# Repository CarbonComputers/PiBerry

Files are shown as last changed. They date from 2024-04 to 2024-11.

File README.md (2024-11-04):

# PiBerry v7.0-7.5 comes with built-in battery power, charging, and keyboard circuit
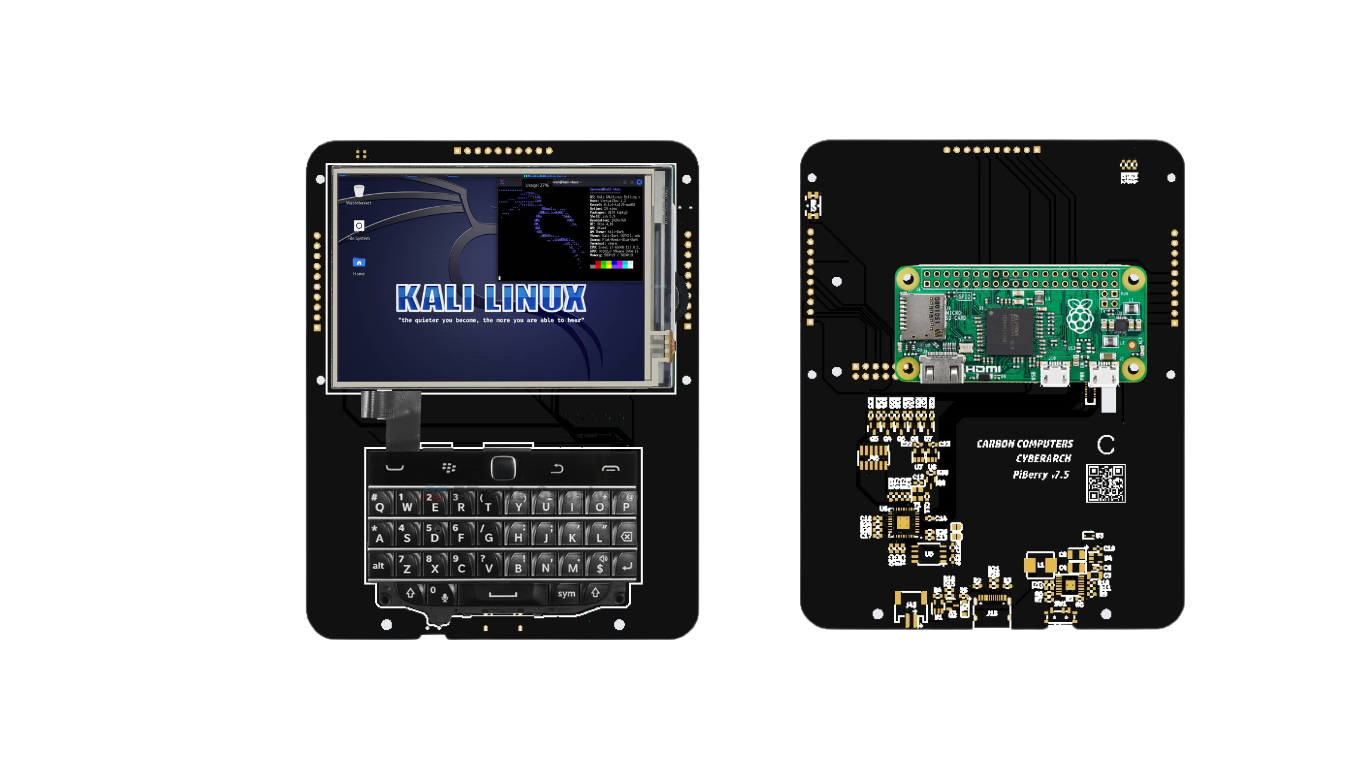
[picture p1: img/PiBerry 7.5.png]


# PiBerry v1.5-v1.8 for a plug & play build
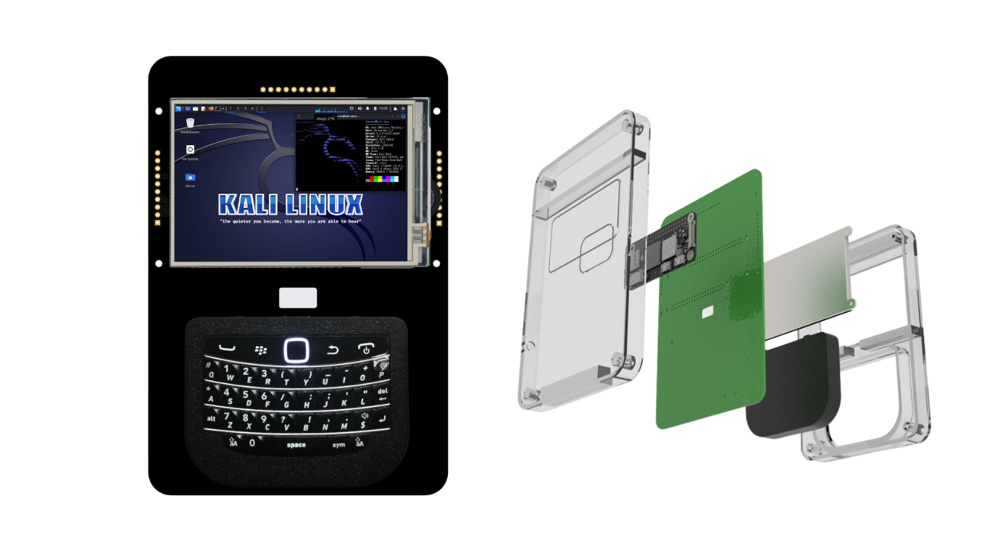
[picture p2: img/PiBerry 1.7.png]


### [Buy Ours Here](https://carboncomputers.us)

## Getting Started
Check the build-guide PDF for the lastest update on build and setup

1. Use the [Raspberry Pi Imager tool](https://www.raspberrypi.com/software/) to flash an SD card with the latest image
    - Choose the ***Raspberry Pi OS Lite (32-bit) image*** for best speed
    - Click the gear icon to also setup WiFi and SSH or you may use a display and keyboard

2. SSH into the pi and update the kernel and reboot
- If the Pi imager was used, then you have the latest kernel, and may then only use apt-get update, skip reboot, and continue onto part 3
```

sudo apt-get update && sudo apt-get install raspberrypi-kernel
```
```
sudo shutdown -r now
```

3. Run the setup script
```
curl -s https://raw.githubusercontent.com/carboncomputers/piberry/main/pi/setup.sh | bash
```

## Details
- In ```/boot/cmdline.txt```, edit ```fbcon=font:VGA8x8``` to change the font/size if you wish. See [fbcon](https://www.kernel.org/doc/Documentation/fb/fbcon.txt) for more details
- Long holding the "End Call" key (~3 seconds) will trigger KEY_POWER and safely shutdown the pi
- Holding the "End Call" button during power up will put the keyboard into bootloader mode; it will now appear as a USB storage device and you can drag'n'drop the new firmware (\*.uf2) into the drive and it will reboot with the new firmware

------------------------------------------------------------------------------------------------------------

# Giving Credit Where Credit is Due

# Beepy - THE ORIGINAL DEVELOPMENT BOARD - THANK YOU FOR MAKING IT OPEN SOURCE



### [Buy It Here - LIMITED STOCK](https://forms.gle/Q3NCLSjDZwcURxrs8)

Learn more at <a href="https://beepy.sqfmi.com/" target="_blank" rel="noopener noreferrer">https://beepy.sqfmi.com/</a>

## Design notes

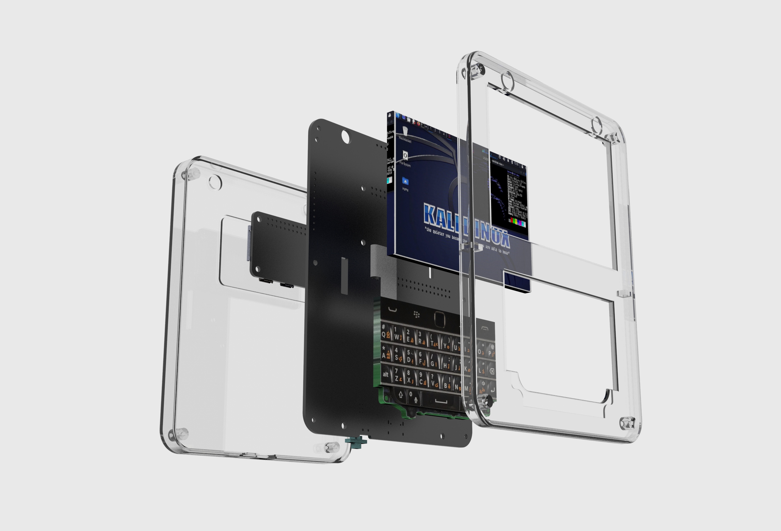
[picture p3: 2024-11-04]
img/v8.0_slim.jpg

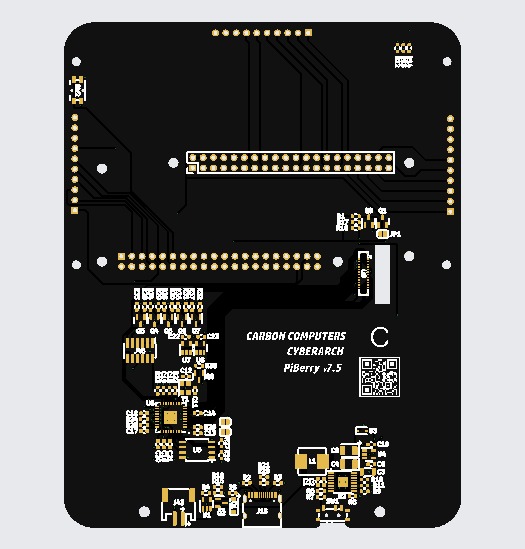
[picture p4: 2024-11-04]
img/PiBerry 7.5 back.jpeg

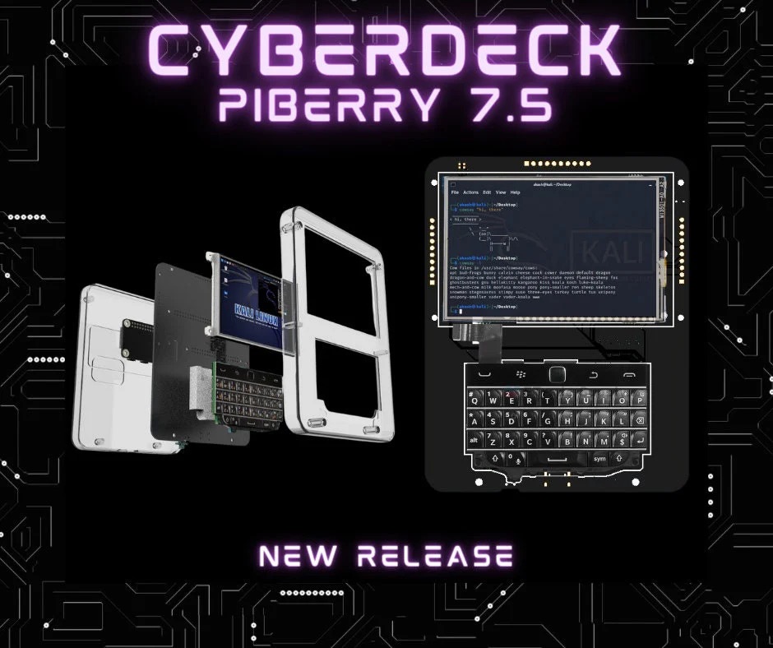
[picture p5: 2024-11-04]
img/7.5.jpeg

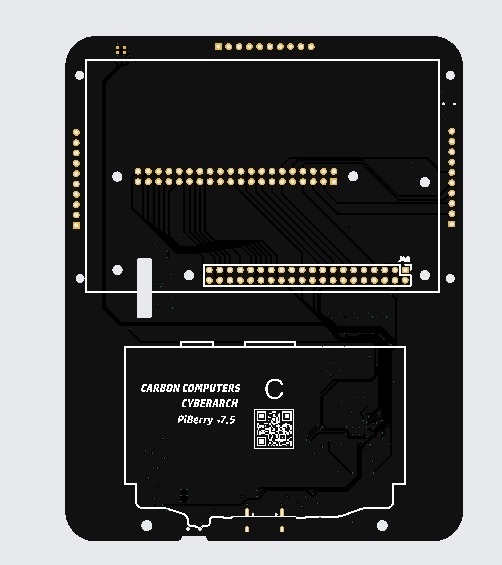
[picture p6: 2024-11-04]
img/PiBerry 7.5.jpeg

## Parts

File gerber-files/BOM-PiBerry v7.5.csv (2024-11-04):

Comment | Designator | Footprint | LCSC
BSS138 | Q3,Q4,Q5,Q6,Q7,Q8 | SOT-23 | C112239
D_Schottky_Small | D3 | D_SOD-323 | C114023
USB_C_Receptacle_USB2.0 | J15 | USB_C_Receptacle_HRO_TYPE-C-31-M-12 | C165948
ME6212C18M5G | U7 | SOT-23-5 | C236669
BBQ20KBD | U9 | BM20B(0.8)-40DS-0.4V | C424543
ME6212C28M5G | U8 | SOT-23-5 | C427596
AP2112K-3.3 | U4 | SOT-23-5 | C51118
XYDBPCNANF-12MHZ | Y1 | Crystal_SMD_3225-4Pin_3.2x2.5mm | C709001
GD25Q16xS | U5 | SSOP-8_5.25x5.24mm_P1.27mm | C79074
RPi_GPIO | J48 | PinHeader_2x20_P2.54mm_Vertical
Notification LED | D2 | FM-B2020RGBA-HG
10K | R1 | R_0603_1608Metric
1K | R22 | R_0603_1608Metric
TPS61090 | U2 | HTSSOP-16-1EP_4.4x5mm_P0.65mm_EP3.4x5mm_Mask2.46x2.31mm_ThermalVias
Button | SW2 | Panasonic_EVQPUL_EVQPUC
10K | R31 | R_0603_1608Metric
1uF | C21 | C_0603_1608Metric
22uF | C3 | C_1206_3216Metric
0.1uF | C17 | C_0603_1608Metric
0.1uF | C22 | C_0603_1608Metric
2M | R6 | R_0603_1608Metric
6.8uH/4A | L1 | L_Bourns_SRP7028A_7.3x6.6mm
220K | R11 | R_0603_1608Metric
27R | R20 | R_0603_1608Metric
100nF | C2 | C_0603_1608Metric
10K | R36 | R_0603_1608Metric
0.1uF | C14 | C_0603_1608Metric
10K | R28 | R_0603_1608Metric
10uF | C10 | C_0603_1608Metric
360K | R7 | R_0603_1608Metric
10K | R30 | R_0603_1608Metric
RP2040 | U6 | QFN-56-1EP_7x7mm_P0.4mm_EP5.6x5.6mm
1K | R27 | R_0603_1608Metric
10uF | C1 | C_0603_1608Metric
10K | R32 | R_0603_1608Metric
100K | R5 | R_0603_1608Metric
0.1uF | C15 | C_0603_1608Metric
4.7K | R25 | R_0603_1608Metric
12pF | C12 | C_0603_1608Metric
220 | R12 | R_0603_1608Metric
10K | R4 | R_0603_1608Metric
TP4054 | U1 | SOT-23-5
330 | R18 | R_0603_1608Metric
0.1uF | C19 | C_0603_1608Metric
10K | R23 | R_0603_1608Metric
10K | R19 | R_0603_1608Metric
27R | R21 | R_0603_1608Metric
100uF | C5 | CP_EIA-3528-15_AVX-H
10uF | C9 | C_0603_1608Metric
10K | R33 | R_0603_1608Metric
10K | R29 | R_0603_1608Metric
Battery | J43 | JST_PH_S2B-PH-SM4-TB_1x02-1MP_P2.00mm_Horizontal
5.1K | R2 | R_0603_1608Metric
S8050 | Q9 | SOT-23
10K | R17 | R_0603_1608Metric
1uF | C18 | C_0603_1608Metric
SI2301 | Q1 | SOT-23
100K | R8 | R_0603_1608Metric
RPi_GPIO | J1 | PinHeader_2x20_P2.54mm_Vertical
100K | R15 | R_0603_1608Metric
4.7K | R24 | R_0603_1608Metric
SI2301 | Q2 | SOT-23
12pF | C11 | C_0603_1608Metric
B5819W | D1 | D_SOD-123
100uF | C4 | CP_EIA-3528-15_AVX-H
1M | R9 | R_0603_1608Metric
10K | R26 | R_0603_1608Metric
10K | R37 | R_0603_1608Metric
100 | R13 | R_0603_1608Metric
10K | R38 | R_0603_1608Metric
10K | R34 | R_0603_1608Metric
0.1uF | C16 | C_0603_1608Metric
100 | R14 | R_0603_1608Metric
10K | R35 | R_0603_1608Metric
0.1uF | C13 | C_0603_1608Metric
ON/OFF | SW1 | SW_SPDT_PCM12
100K | R16 | R_0603_1608Metric
5.1K | R3 | R_0603_1608Metric
2M | R10 | R_0603_1608Metric
PRG_HEADER | J45 | PinHeader_2x06_P1.27mm_Vertical_SMD
0.1uF | C20 | C_0603_1608Metric
0.1uF | C23 | C_0603_1608Metric

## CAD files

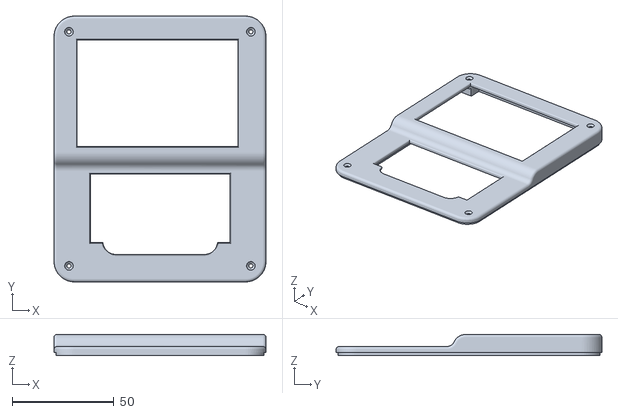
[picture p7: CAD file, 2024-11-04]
3D-STL/upper_part_v8.0.2_retro_rev1.stl
104.0 x 130.4 x 10.4

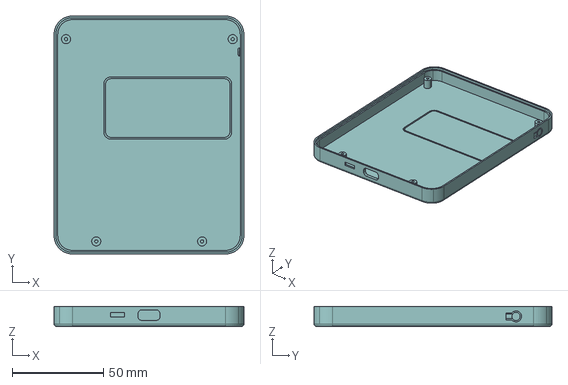
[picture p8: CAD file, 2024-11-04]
step-files/lower_part_v7.5.1.stp
104.0 x 130.4 x 11.1 mm

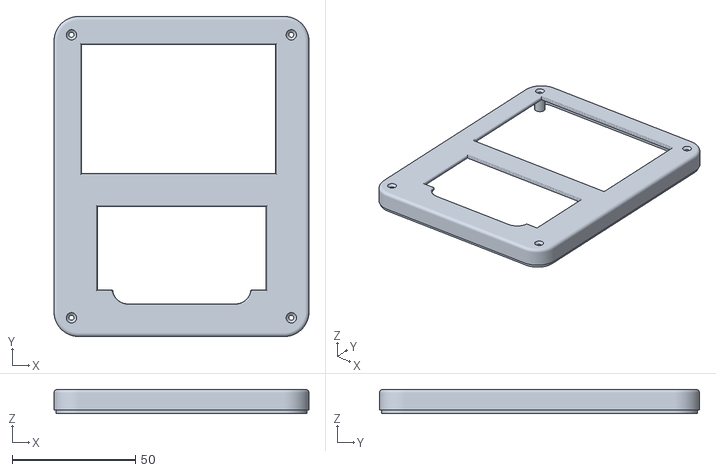
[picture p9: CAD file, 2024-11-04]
3D-STL/upper_part_v8.0.1_1.5mm.stl
103.5 x 129.9 x 9.94

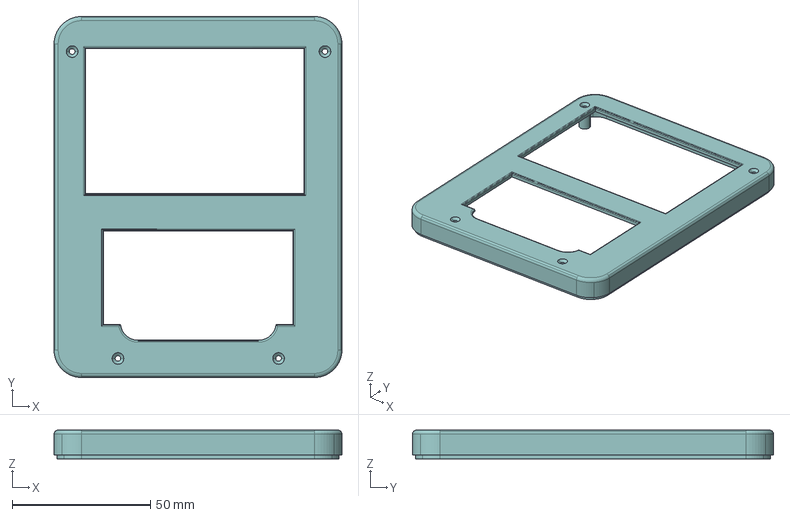
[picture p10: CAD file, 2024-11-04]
step-files/upper_part_v7.5.1.stp
104.0 x 130.4 x 10.4 mm

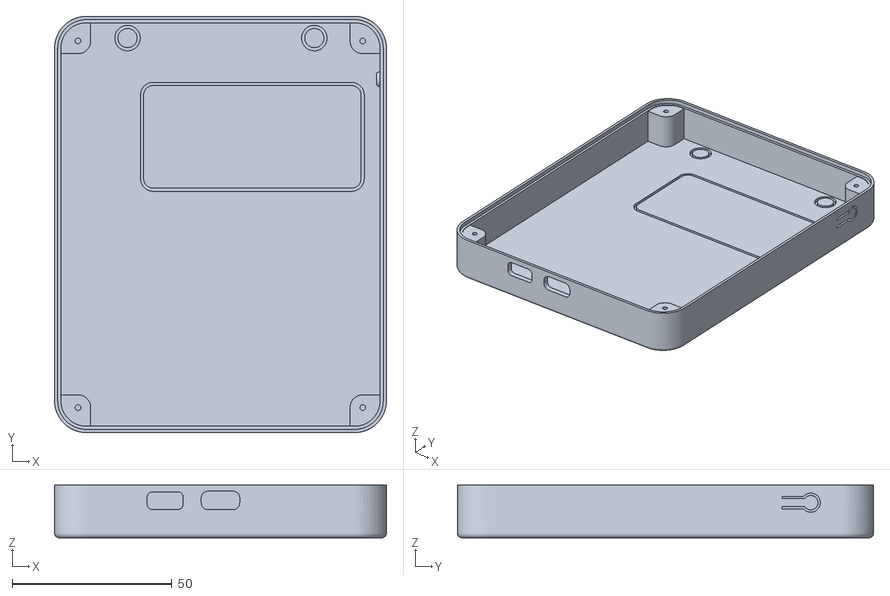
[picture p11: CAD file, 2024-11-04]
3D-STL/Print 3x -New_lower_part_v8.0.2_rev2.stl
104.0 x 130.4 x 16.5

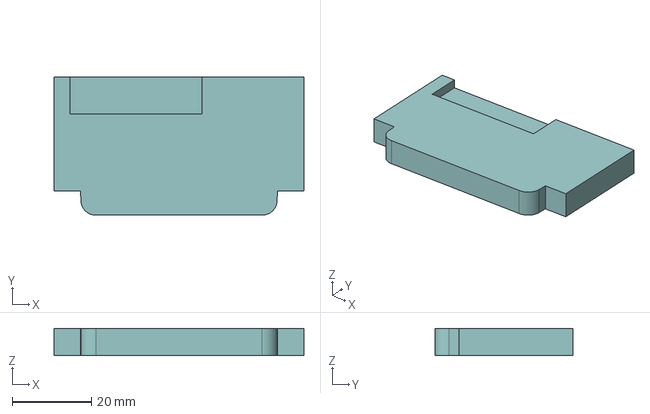
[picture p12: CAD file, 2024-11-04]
step-files/keyboard_spacer.stp
63.1 x 34.8 x 6.90 mm

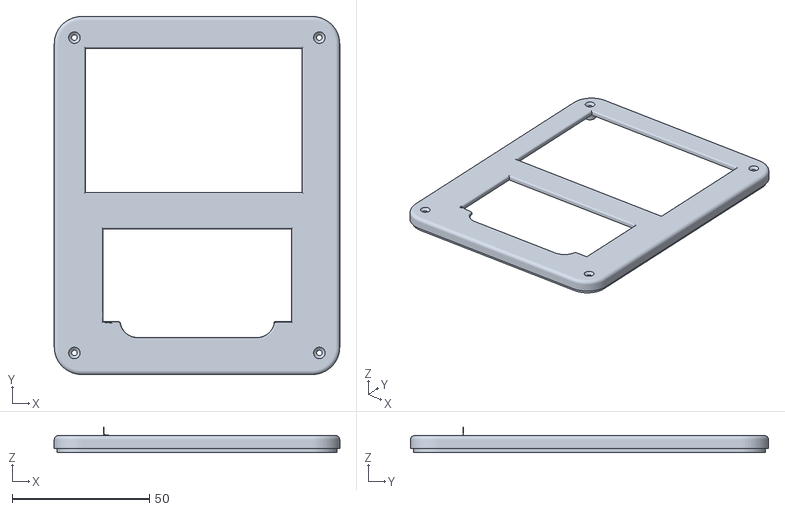
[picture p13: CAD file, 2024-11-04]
3D-STL/upper_part_v8.0_slim_screen.stl
104.0 x 130.4 x 9.14

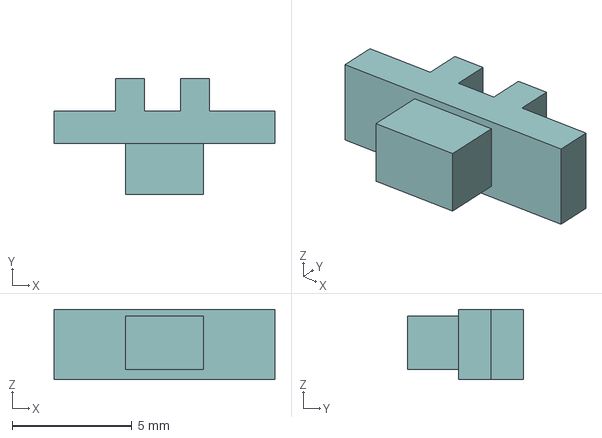
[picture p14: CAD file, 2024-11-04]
step-files/switch_slider.stp
9.24 x 4.84 x 2.93 mm

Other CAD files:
3D-STL/keyboard_spacer.stl

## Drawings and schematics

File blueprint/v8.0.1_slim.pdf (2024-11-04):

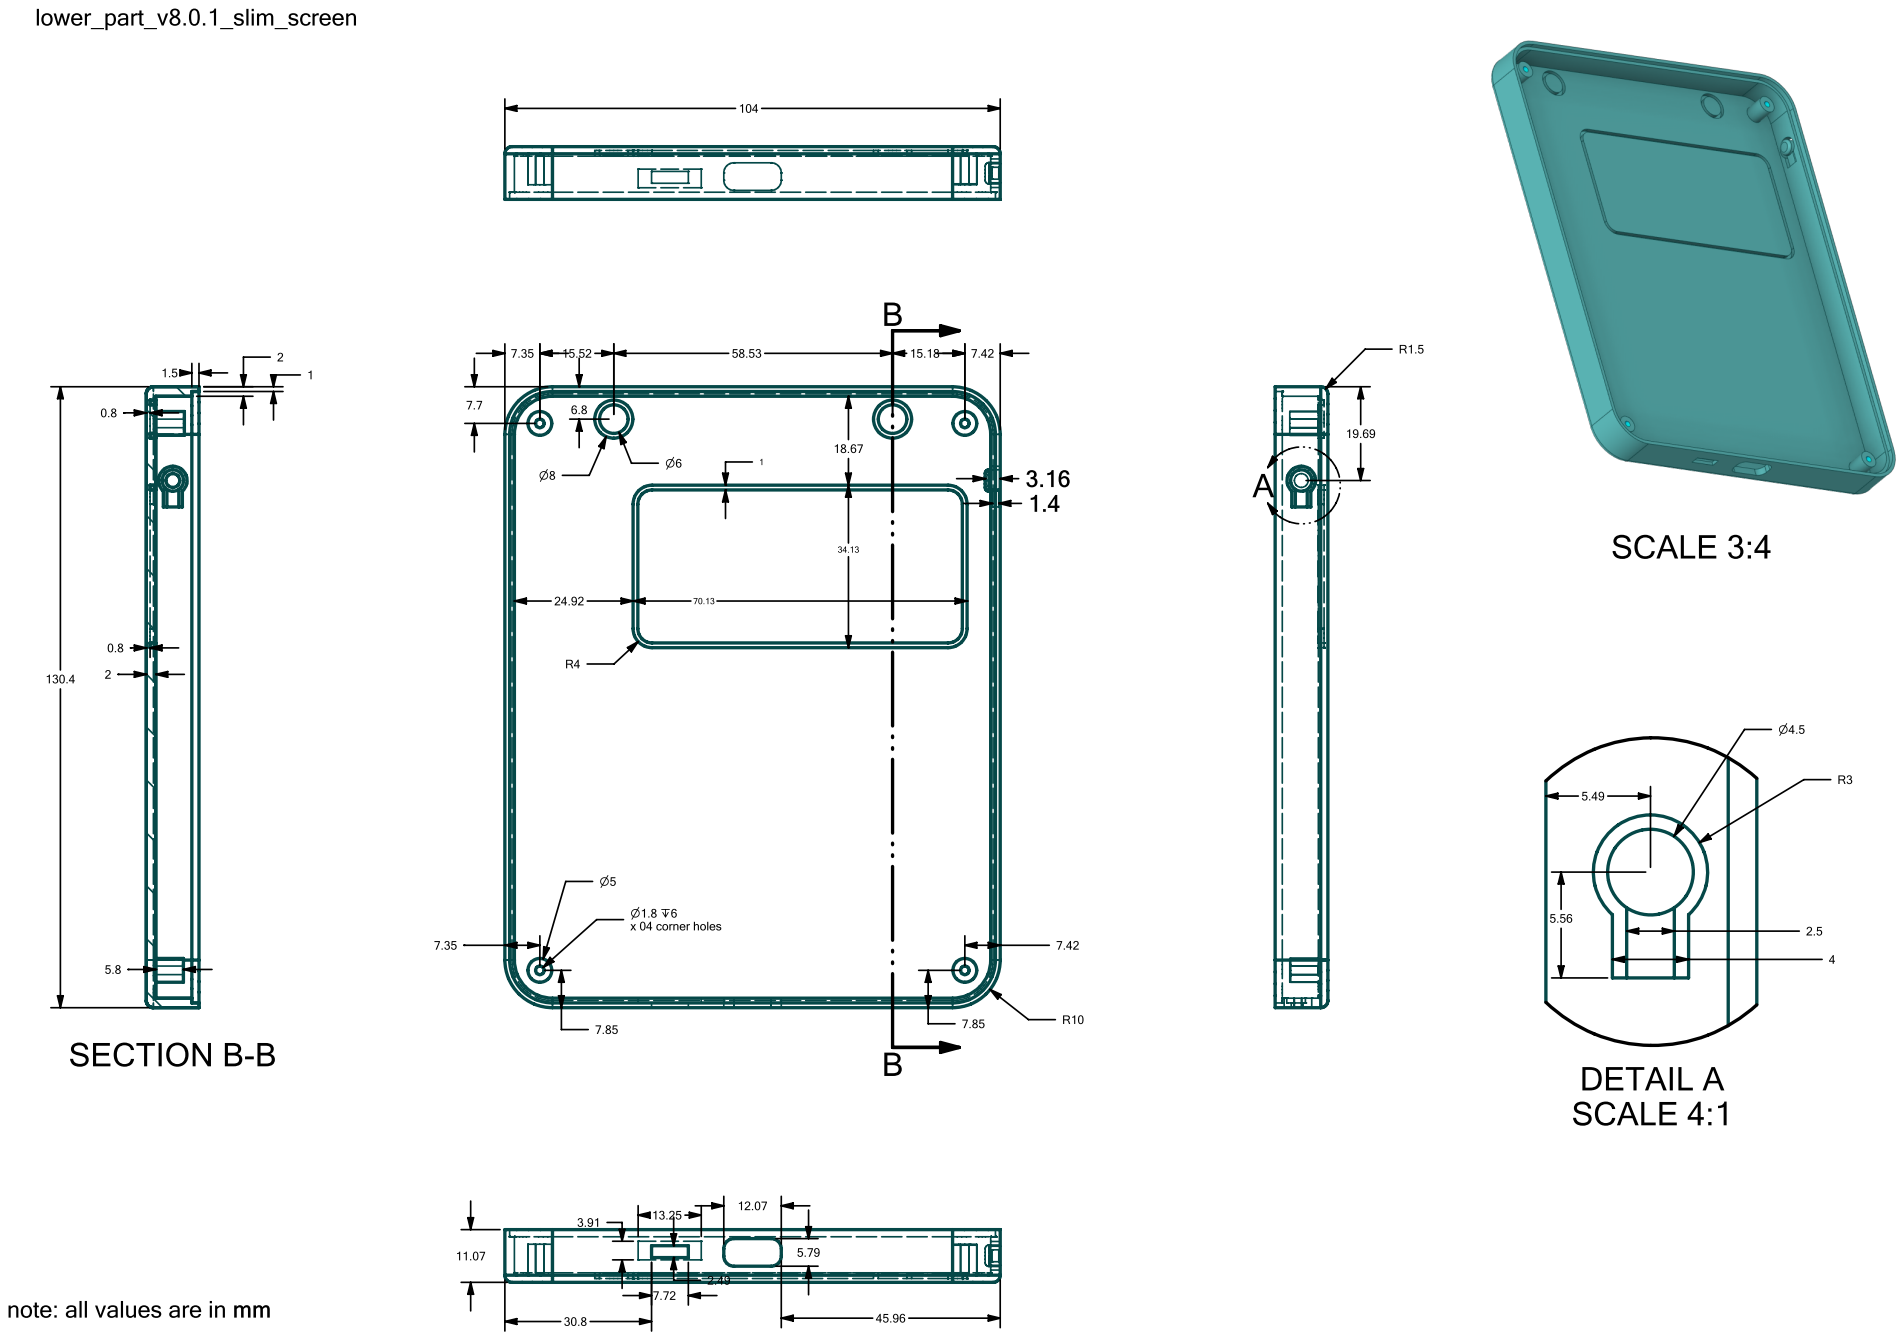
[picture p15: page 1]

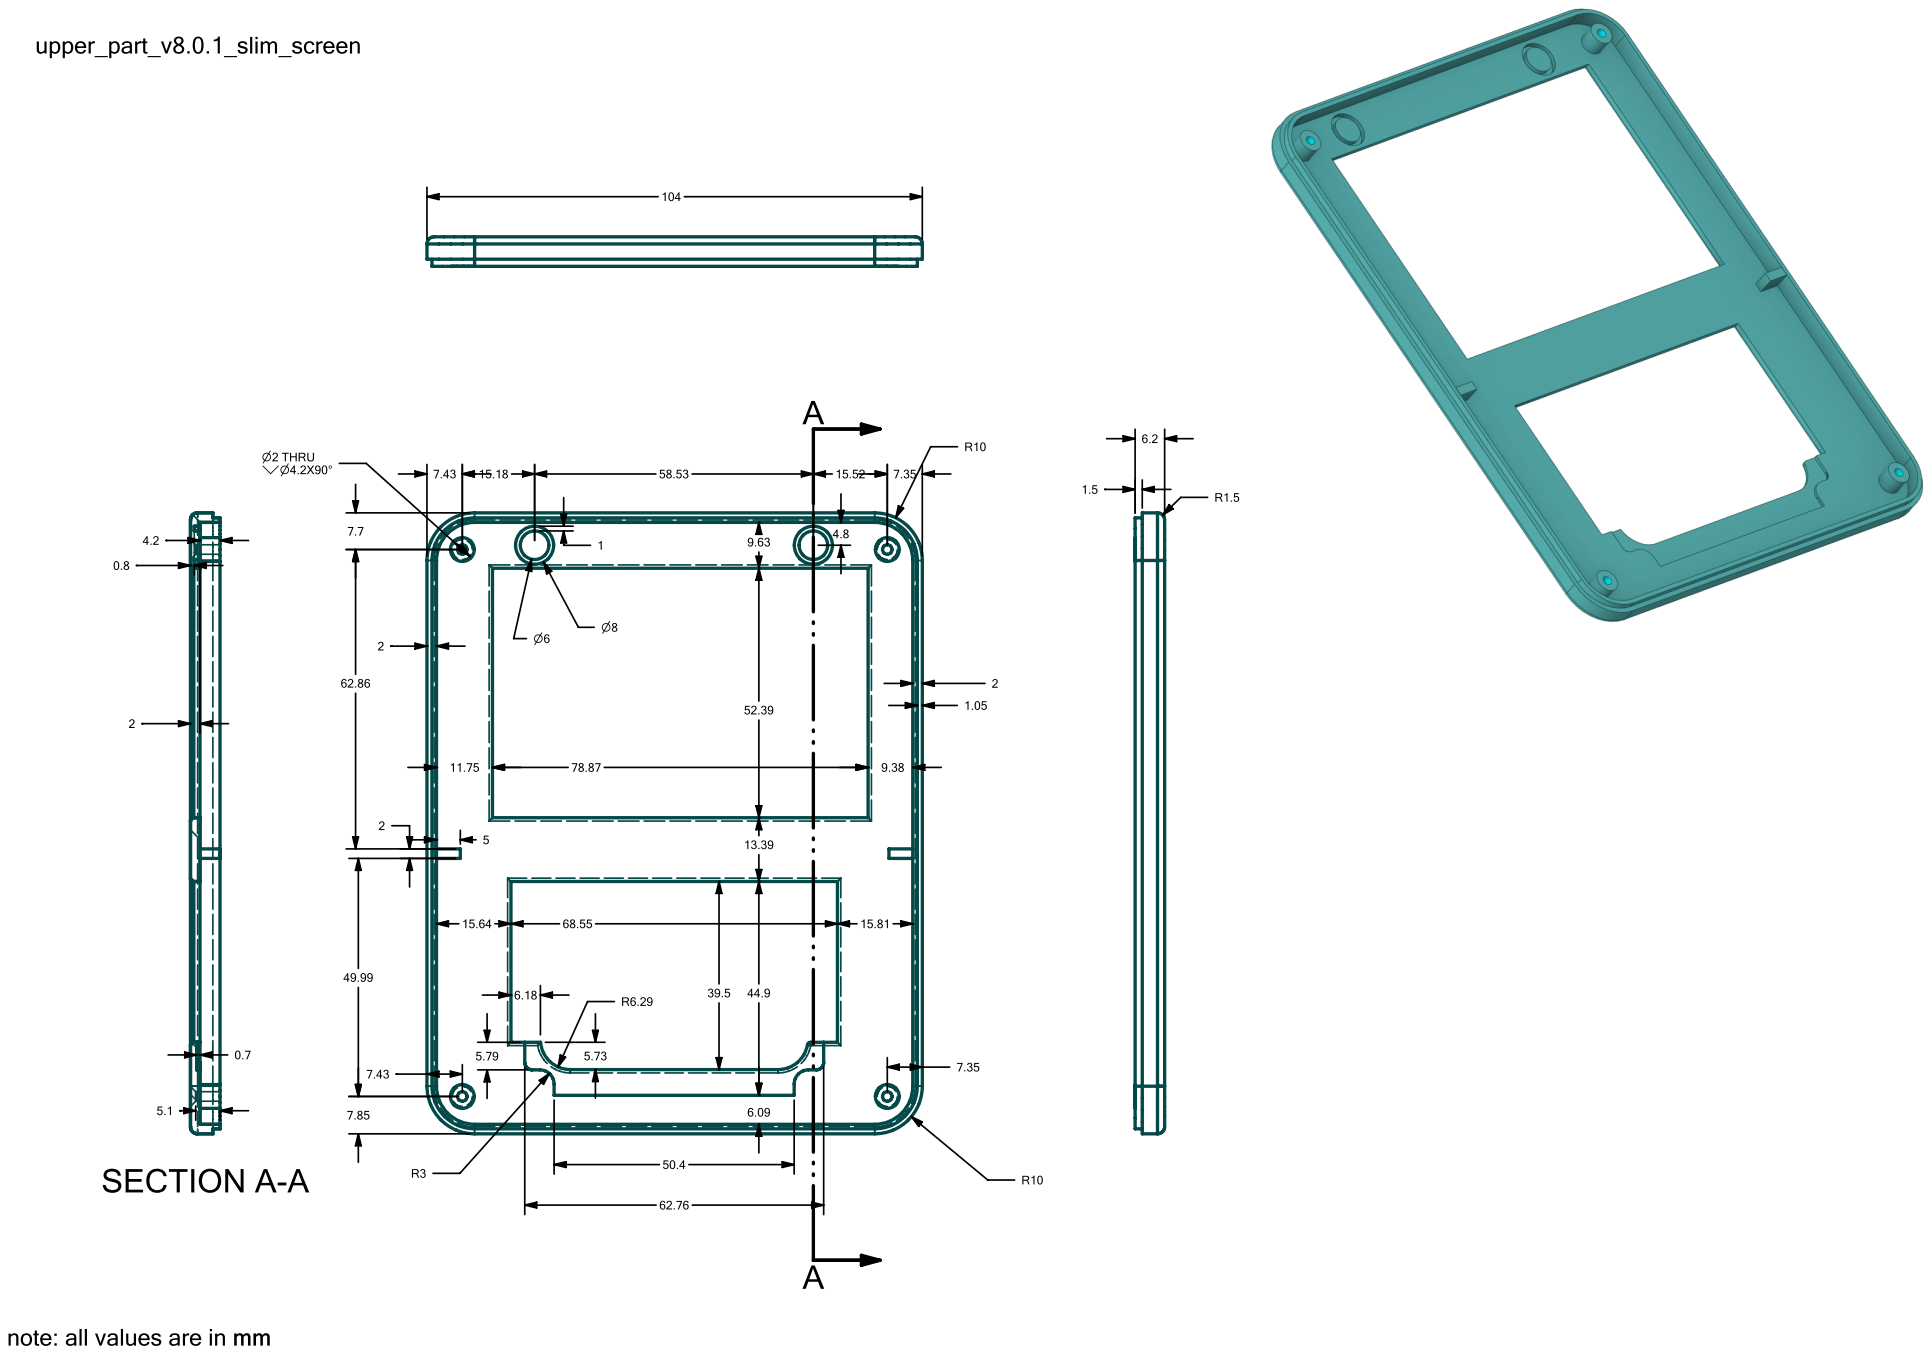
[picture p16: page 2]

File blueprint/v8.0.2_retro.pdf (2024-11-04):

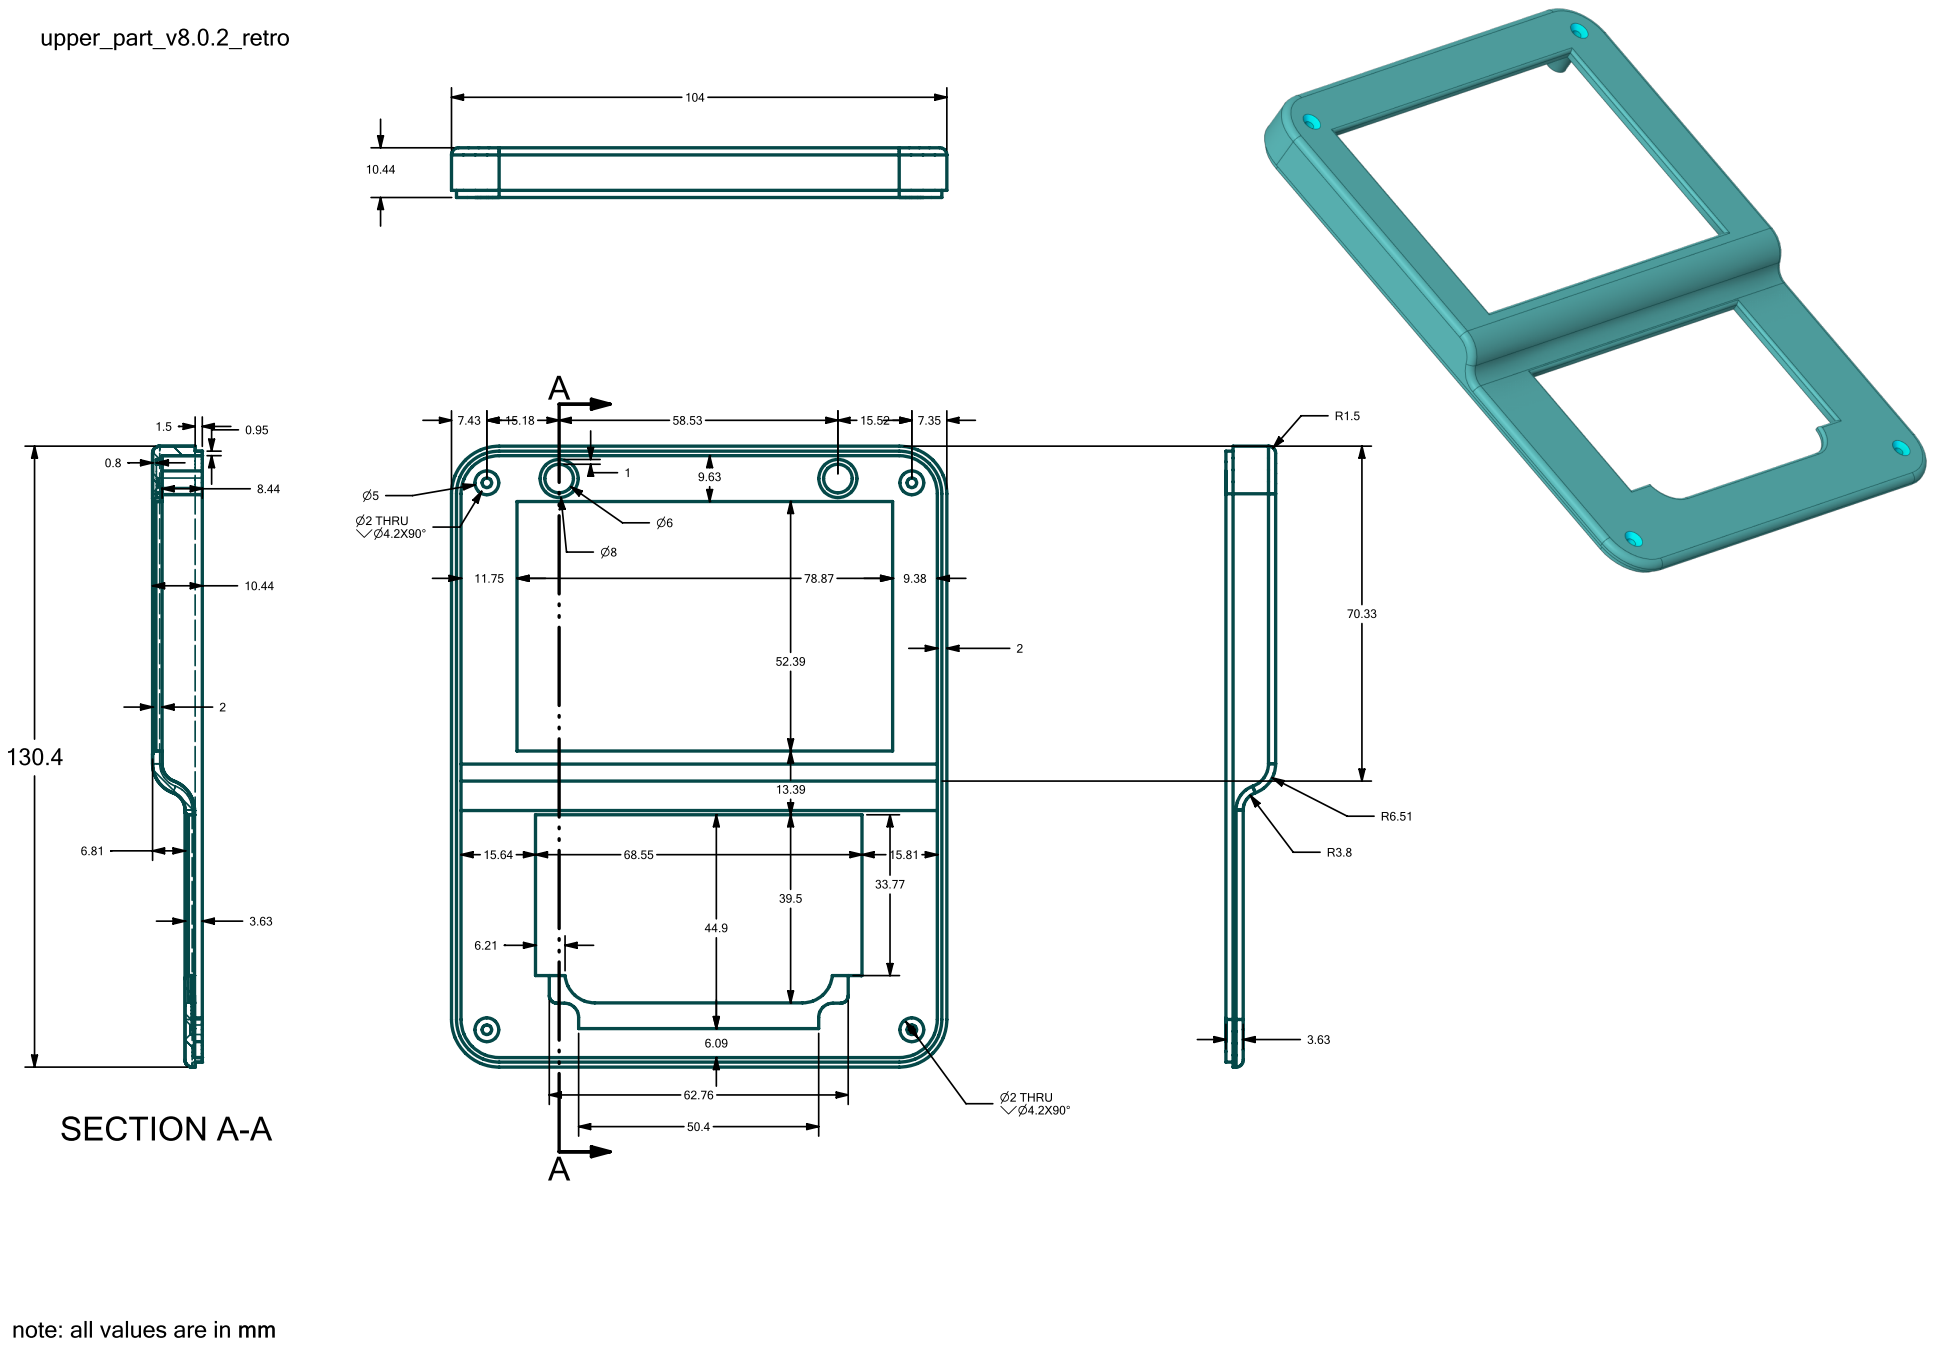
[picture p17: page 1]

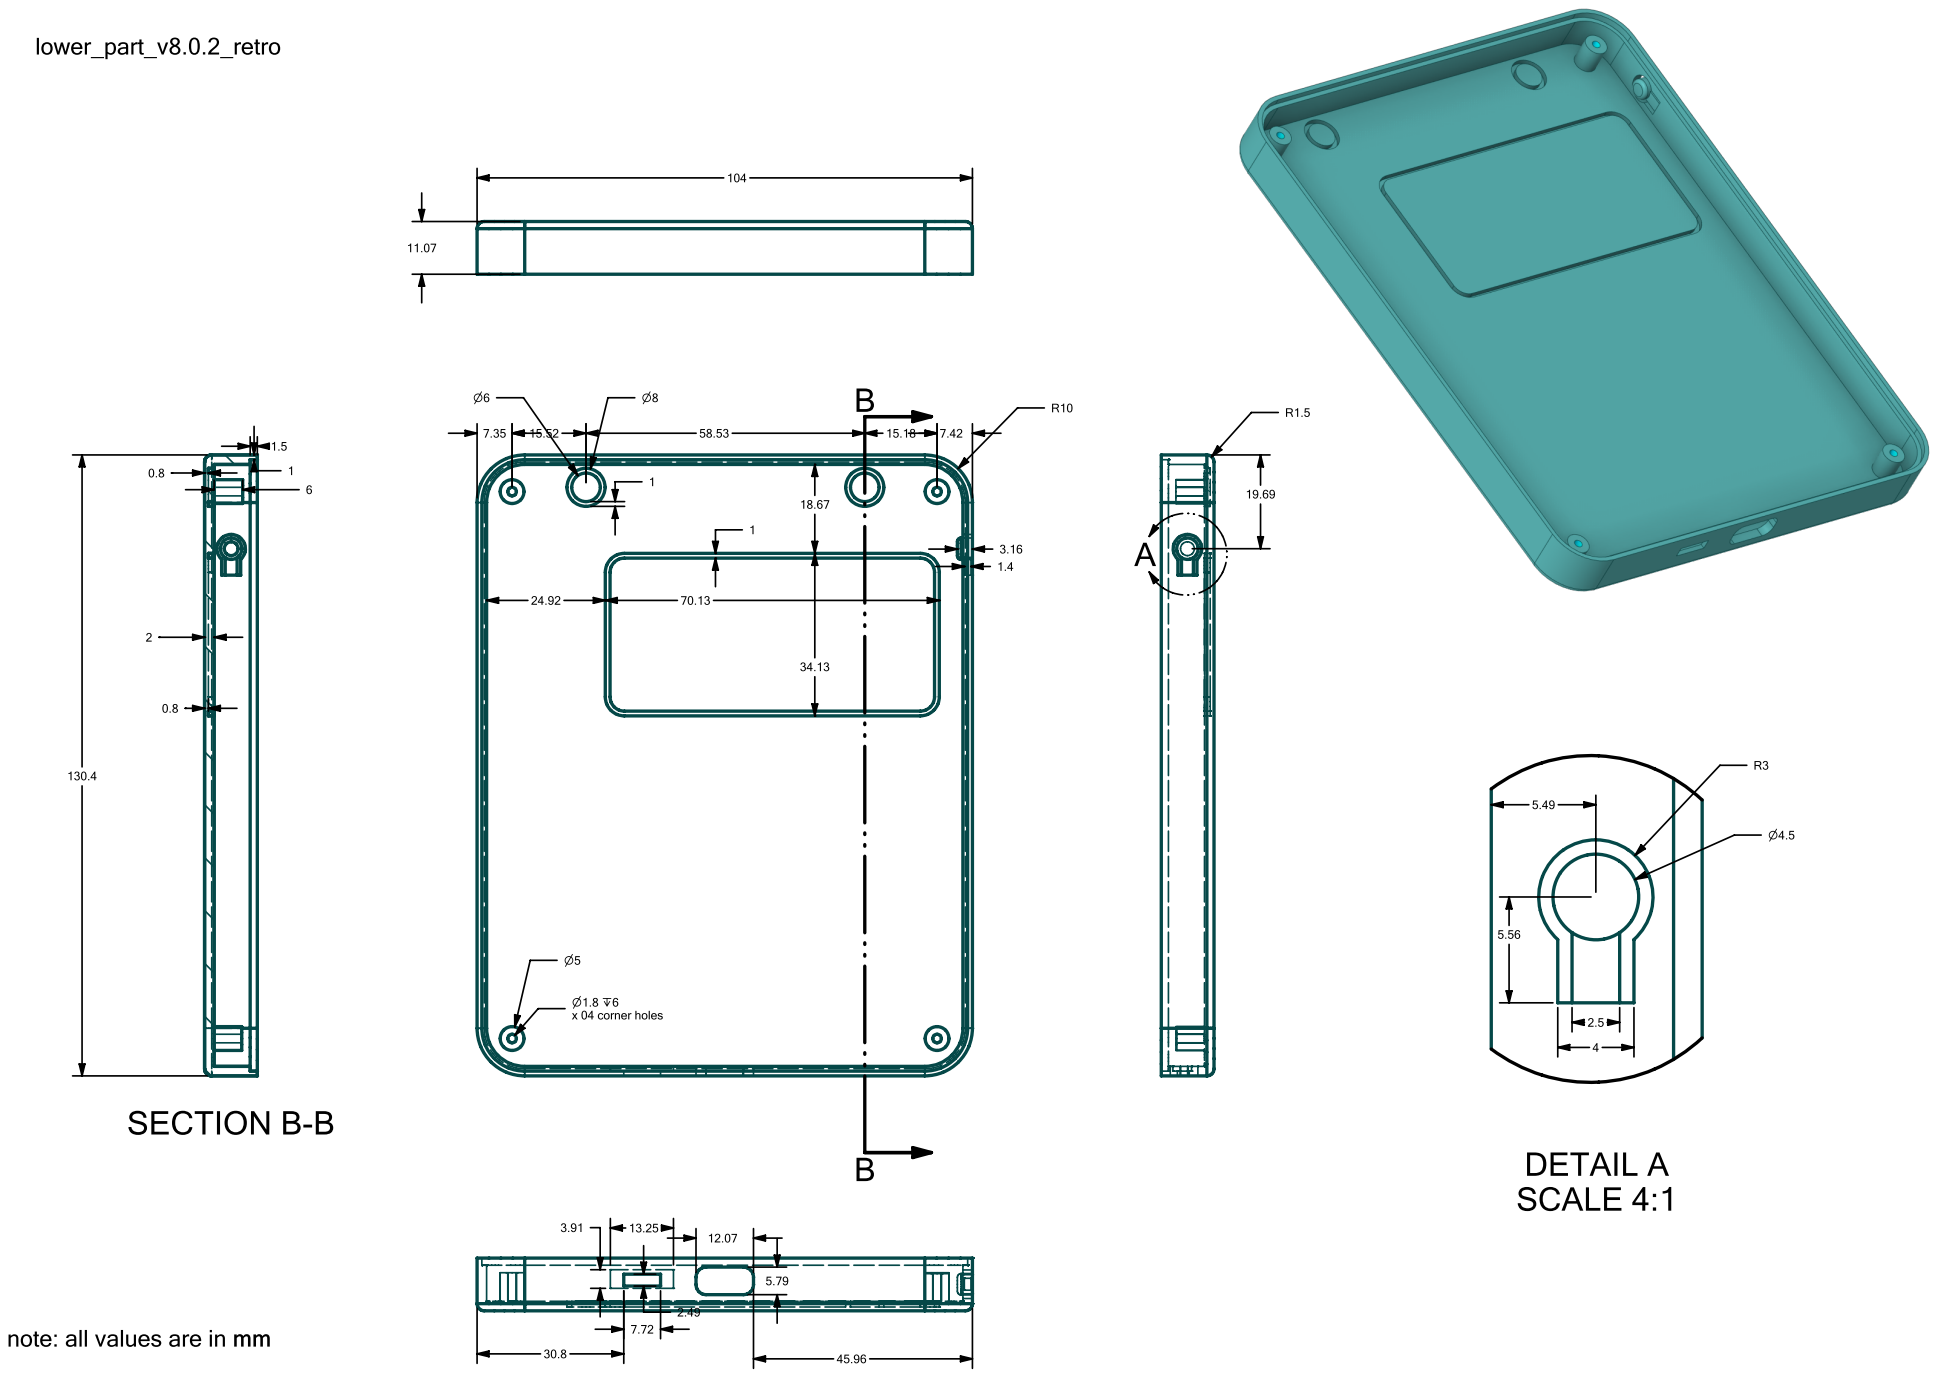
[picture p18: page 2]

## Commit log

2024-04-19 Update for PiBeery Build.sh
    Commented out the display driver
2024-11-04 piblishing PiBerry 7.5
    [BOM-PiBerry v7.5.csv, Print 3x -New_lower_part_v8.0.2_rev2.stl, keyboard_spacer.stl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]
